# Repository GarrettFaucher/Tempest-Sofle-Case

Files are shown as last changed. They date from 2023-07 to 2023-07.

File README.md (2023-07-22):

# Tempest Sofle V2 case

<a href="https://www.paypal.com/donate/?hosted_button_id=LNPV4WR7C95VA">

A 3D printed, case for the Sofle v2.0w keyboard




---

### --> [Original Sofle keyboard repository](https://github.com/josefadamcik/SofleKeyboard)

### --> [Original Elmo Case Repository](https://github.com/kb-elmo/SofleCase)

### --> [Pehmis Case Repository](https://github.com/Pelicram/Pehmis-Sofle-Case)

**Please note that the v2.0, v2.0w, and 42keebs V2.1 versions are compatible with this case. The V2.1 Sofle with per-key RGB is not compatible.**

---

## Assembly materials needed

* **10x** m2x8mm screws for the cases.
* **20x** m2x4mm screws for the plates (If you bought a sofle kit these should be included).
* **10x** m2x8mm standoffs for the pcbs (If you bought a sofle kit these should be included).
* **10x** m2x4x3.5mm heat-set threaded inserts to screw the cases together.
* **16x** 8mm rubber bumpons (optional).

## Changes to Pelicram's case

* Removed bottom contouring that created tenting
* Removed wrist rest support
* Enlarged hole for nice!nano and switch
* Added removable nice!view cover
* Added slot for 450mAh 403040 battery

## Please note

* The included knob is designed for the Alps EC11 encoder with a 15mm tall plum shaft.  [Such as this one.](https://www.aliexpress.com/item/1005002767327743.html)
If you are using a different model you might have to use a different knob for your board.
* 3MF files are oriented for best print results and don't require supports.

## Assembly instructions

1. Assemble the Sofle keyboard like you would normally, but don't screw the fr4/acrylic bottom on. 
2. Instead screw the keyboard halves into `Bottom` with the `m2x4mm` screws.
3. Install the heat-set threaded inserts into the holes in `Top`.
4. Slot the case bottoms into the tops, and screw together with the `m2x8mm` screws.
5. Slot nice!view cover into `Top`
5. Install `Knob-X2` into the encoders.

## Special Thanks to

* Josef Adamcik for designing the original Sofle keyboard and making the project open source.
* kb-elmo for making the original version of this case and sharing the step files.
* Pelicram for modifying kb-elmo's design

---

These files are meant for 3D printing only! 

They are not suitable for CNC machining and trying to use them for that will most likely result in unusable parts.

---

_Licensed under a
[Creative Commons Attribution-NonCommercial-ShareAlike 4.0 International License][cc-by-nc-sa]._

[cc-by-nc-sa]: http://creativecommons.org/licenses/by-nc-sa/4.0/

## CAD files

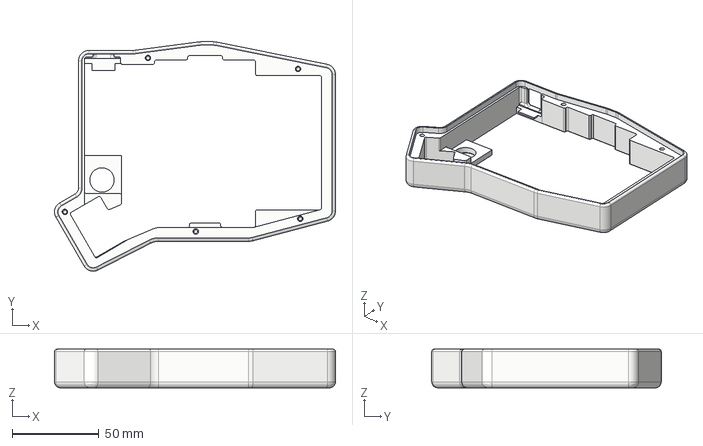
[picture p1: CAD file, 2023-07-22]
STEP/Tempest Top.step
161.6 x 132.0 x 22.3 mm

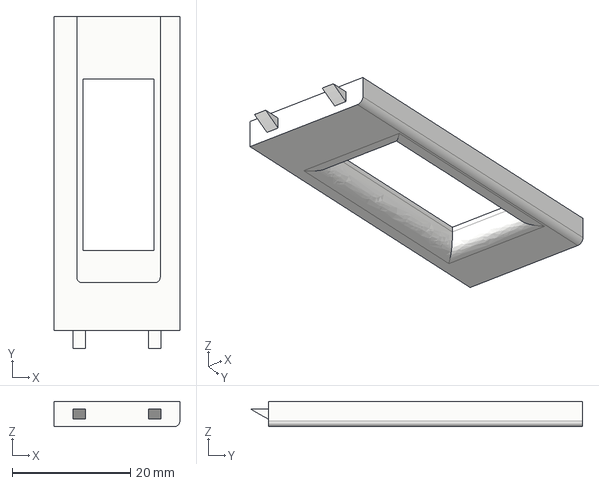
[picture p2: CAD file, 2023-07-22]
STEP/Tempest Cover.step
21.2 x 56.1 x 4.30 mm

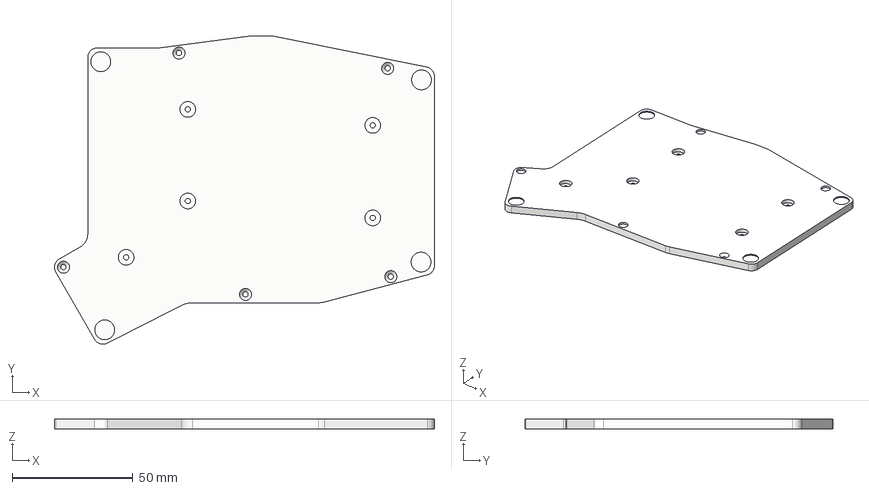
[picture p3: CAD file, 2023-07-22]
STEP/Tempest Bottom.step
157.2 x 127.6 x 4.00 mm

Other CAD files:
3MF/Tempest Bottom.3mf
3MF/Tempest Cover.3mf
3MF/Tempest Top.3mf

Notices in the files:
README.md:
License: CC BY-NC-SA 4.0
